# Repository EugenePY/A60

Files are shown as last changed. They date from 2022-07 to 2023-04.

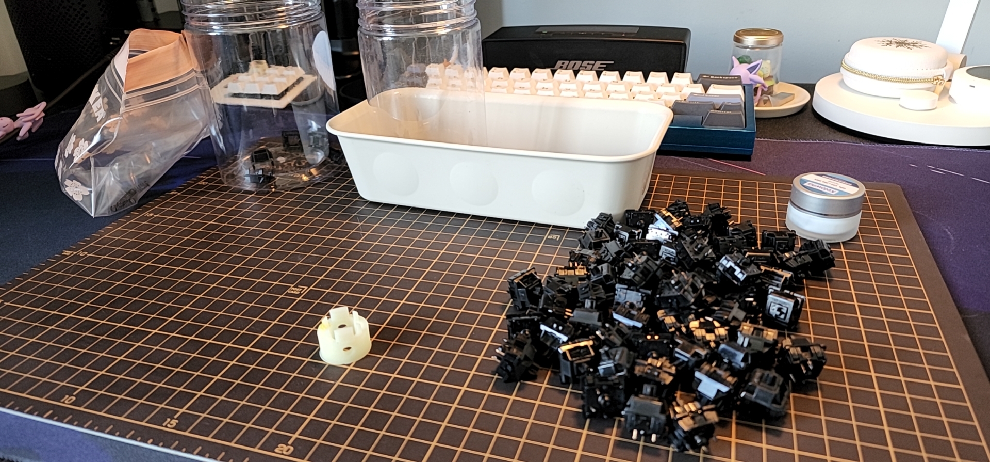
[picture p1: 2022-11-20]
Photo Shoots/wx_camera_1661579096359.jpg

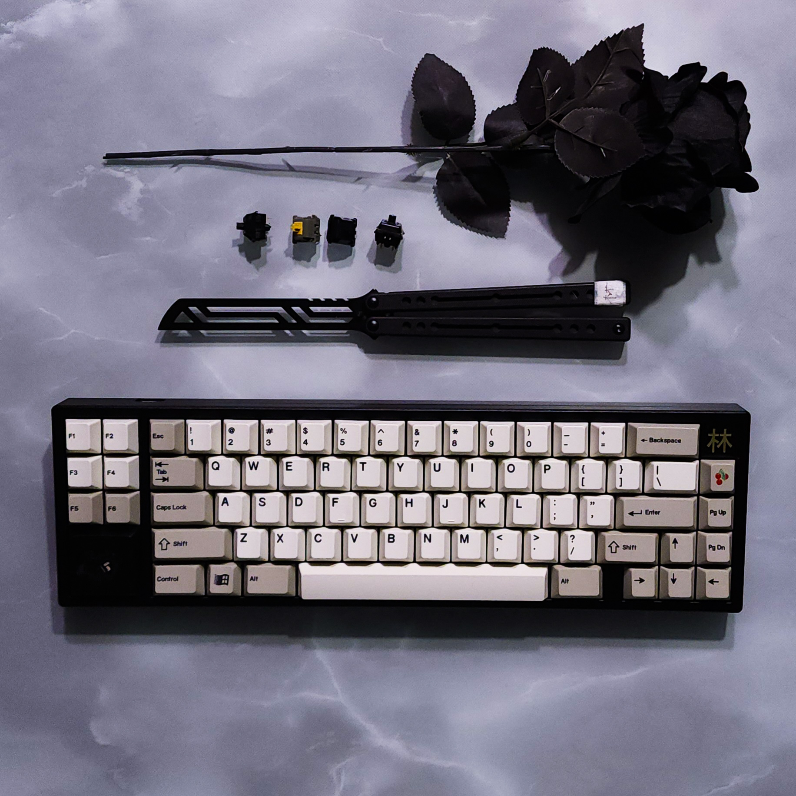
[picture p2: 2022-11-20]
Photo Shoots/20221017_020129.jpg

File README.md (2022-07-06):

# Forest 65 PCB

Hi, Andrew nice work!

Since you are using the web based eda tool, I generaly do not have any problems 
with them. It's very simple and having great integration with the pcb/eletronic 
component firms, but I suggest you still need to learn KiCAD, 

There are few benifit about kicad. 

1. it's open sourced.
2. it has a great supported by the eda/keyboard community.

Most of open sourced EE project are using kicad as their tools, and some of 
professional still prefer it to some commercial EDAs like EAGLE, Altium. 

there are many learning resource for kicad, one of most popular one is the 
[Ai03's Keyboard Guide](https://wiki.ai03.com/books/pcb-design/page/pcb-guide-part-1---preparations)

You may follow it to know how to use kicad. Kicad also has a lot of open sourced footprint libarary.

1. [Ai03's Mx Switch Footprint](https://github.com/ai03-2725/MX_Alps_Hybrid.git)
2. [Acherion Project Gondolindrim](https://github.com/AcheronProject)

# For current PCB files

I  add datasheet about ATMEGA32U4-AU, you can check your pins, reading the 
datasheet maybe very overwhelming in the first place, but I still recommanded 
to go through it. It's very benifitcial for you in the long run since you want 
to get into eletronic desin/EE. And other datasheet follows the similar priciple.

# TODOs

1. Please rewire your pcb in kicad.

# PCB comments

I think your pcb works, but there are few things need to be improved.
    
### The wire should not be too close to the pcb edge if the space allowed. 

    If the wire are too close to the edge it may break easily, but it just a 
    minor things to notice, generaly it does not affect overall functionality.

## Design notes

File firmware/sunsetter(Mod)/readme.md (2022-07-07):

# Sunsetter

Sunsetter

A 65 + 10% F-Key Column Keyboard kit made and sold by Charue Design. [More info on charue-design.com](https://charue-design.com/)

* Keyboard Maintainer: [Coarse](https://github.com/coarse)
* Hardware Supported: [Sunsetter PCB](https://charue-design.com/collections/sunsetter/products/sunsetter-pcb-extra)
* Hardware Availability: [Charue Design](https://charue-design.com/)

#### Jumping to Bootloader

To enter the bootloader, you may use bootmagic by holding `Space+B` or by holding the reset button located at the back of the PCB, right beside the left shift key, for a few seconds.

Make example for this keyboard (after setting up your build environment):

    make charue/sunsetter:default

See the [build environment setup](https://docs.qmk.fm/#/getting_started_build_tools) and the [make instructions](https://docs.qmk.fm/#/getting_started_make_guide) for more information. Brand new to QMK? Start with our [Complete Newbs Guide](https://docs.qmk.fm/#/newbs).

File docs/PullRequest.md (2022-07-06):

# A60-PCB

If you are using github gui, I suggest you using commandline, haha.

[some basics](https://www.earthdatascience.org/workshops/intro-version-control-git/basic-git-commands/)

__To make me to have your code in my repo(Create a pull request to upstream repo)__ 

there are few steps to do.

1. Fork my project
2. Clone your repo
3. Add your pcb files to your repo, and commit it in the git tree.
4. Create a pull request to my repo.

# Fork my project

Since the repo is public, so the project can be accessed for everyone. The 
first step to collabration with other developer is to fork their project. 
Forking a project means to create a parallel branch. It can be seen as your version of source code.

Please read the following document for further details about how fork my project.
https://www.earthdatascience.org/workshops/intro-version-control-git/about-forks/

# Clone Your project

Once you create a fork of my project, you should see a new repo in your own 
github accout, and the content is same as mine. Please clone the repo from your own github account.

```
git clone https://github.com/YOUR-USERNAME/YOUR-REPOSITORY
```

you should type in your commandline or terminal.

```
git clone https://github.com/TimalU27/A60.git
```

# Add pcb files to your repo and commit your changes.

then add your sorce code to the git tree.

the add files to your repo please type following command. the command means 
add all files under your root directory.

```
git add .
```

to commit 

```
git commit -m "your commit message"
```

# Create a pull request to my repo.

[How to do a github pull request](https://stackoverflow.com/questions/14680711/how-to-do-a-github-pull-request)

good luck.

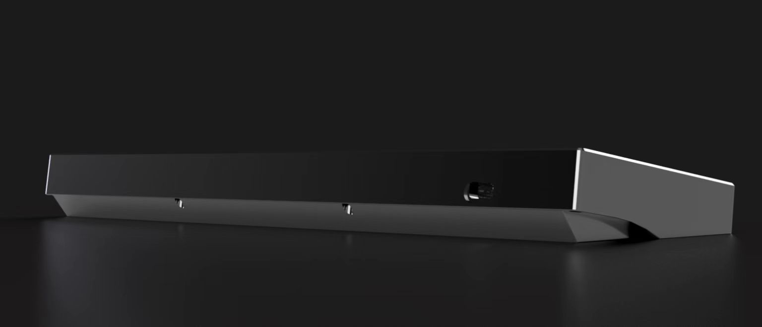
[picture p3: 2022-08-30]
render/render v2/Back.jpg

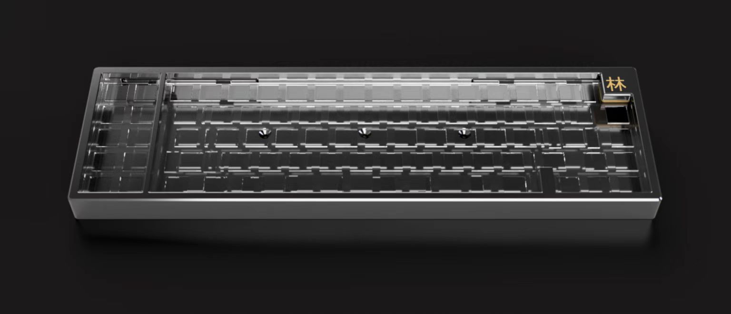
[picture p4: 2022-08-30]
render/render v2/Top.jpg

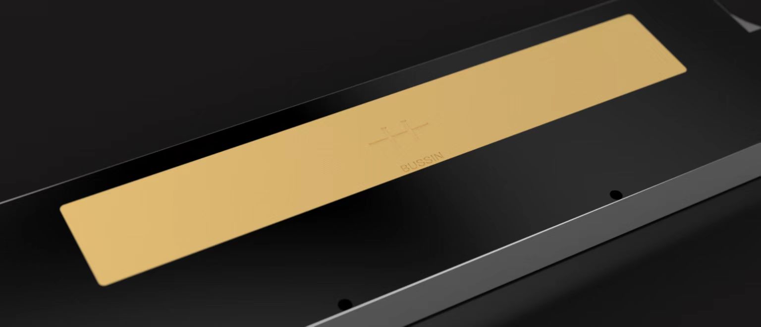
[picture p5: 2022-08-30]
render/render v2/Weight.jpg

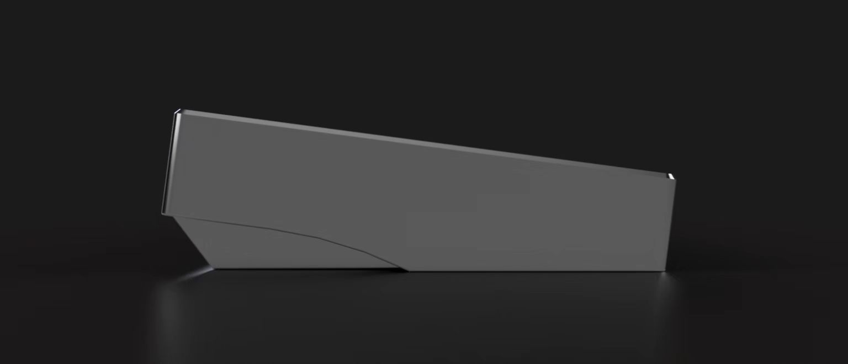
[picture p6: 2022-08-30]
render/render v2/side.jpg

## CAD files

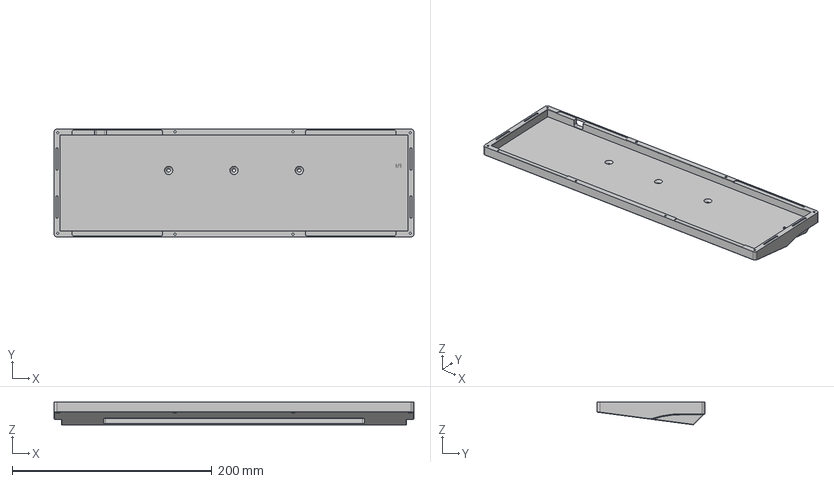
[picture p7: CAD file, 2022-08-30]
3d/bottom.step
360.6 x 108.2 x 22.7 mm

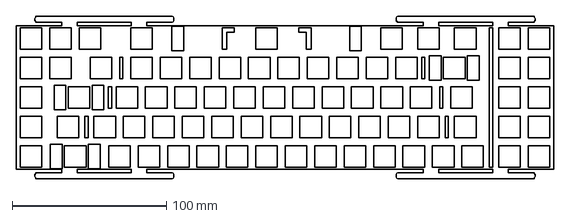
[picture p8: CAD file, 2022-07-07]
plate felx.dxf
347.7 x 105.2 mm

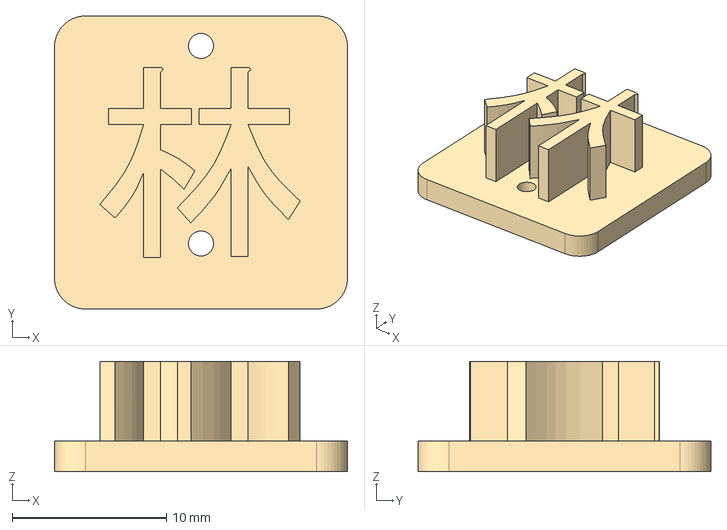
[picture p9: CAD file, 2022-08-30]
3d/badge.step
19.0 x 19.0 x 7.15 mm

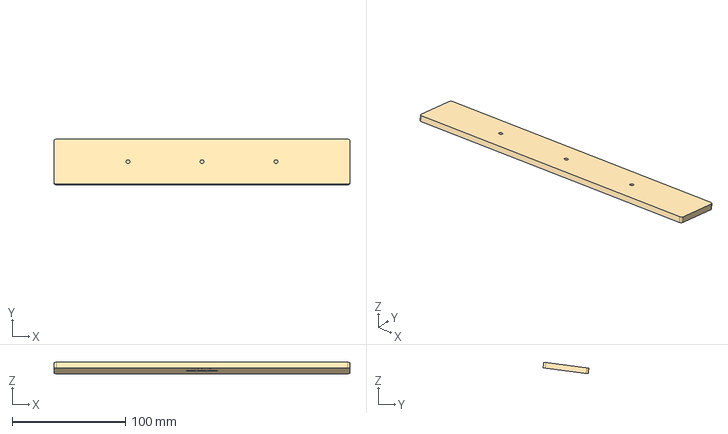
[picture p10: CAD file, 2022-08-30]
3d/Weight.step
261.7 x 40.6 x 10.2 mm

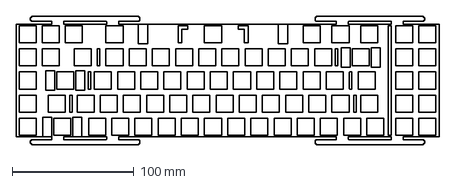
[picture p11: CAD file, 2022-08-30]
3d/plate.dxf
347.7 x 105.2 mm

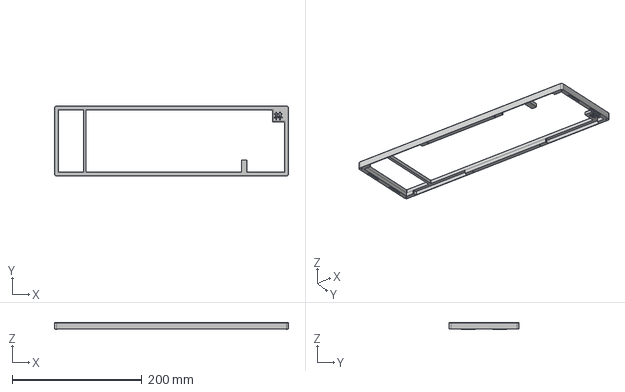
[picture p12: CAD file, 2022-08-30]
3d/top.step
360.6 x 108.2 x 11.5 mm

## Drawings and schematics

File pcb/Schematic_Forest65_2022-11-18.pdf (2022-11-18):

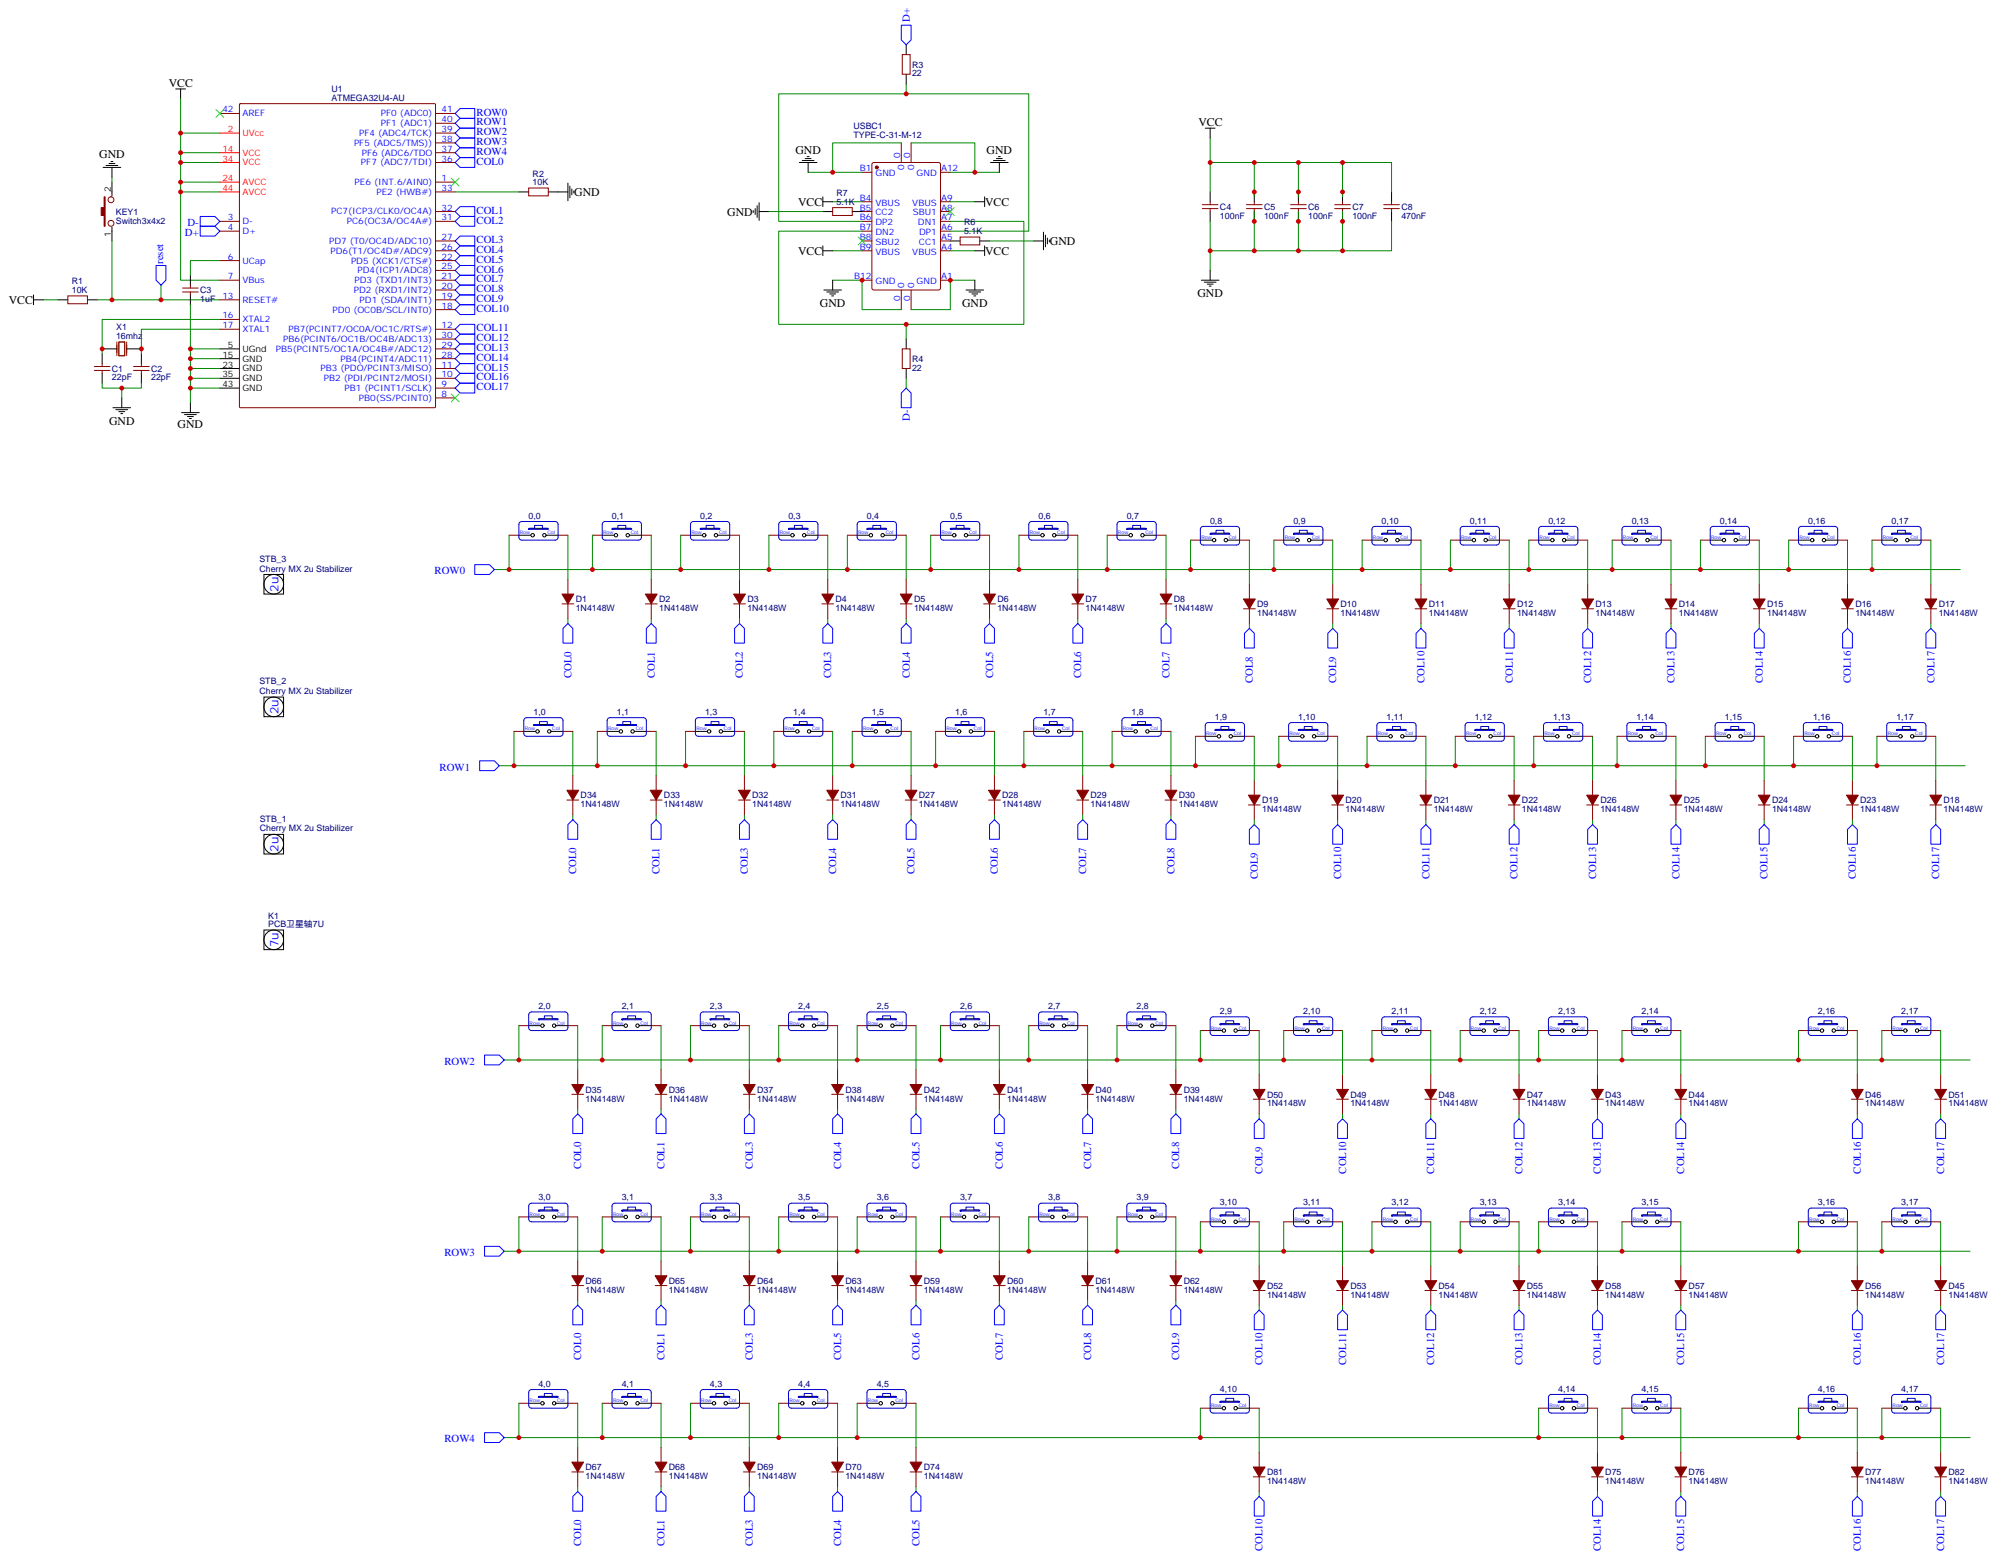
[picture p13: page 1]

PB7(PCINT7/OC0A/OC1C/RTS#) 12
PB2 (PDI/PCINT2/MOSI) 10 PB3 (PDO/PCINT3/MISO) 11 PB4(PCINT4/ADC11) 28 PB5(PCINT5/OC1A/OC4B#/ADC12) 29 PB6(PCINT6/OC1B/OC4B/ADC13) 30

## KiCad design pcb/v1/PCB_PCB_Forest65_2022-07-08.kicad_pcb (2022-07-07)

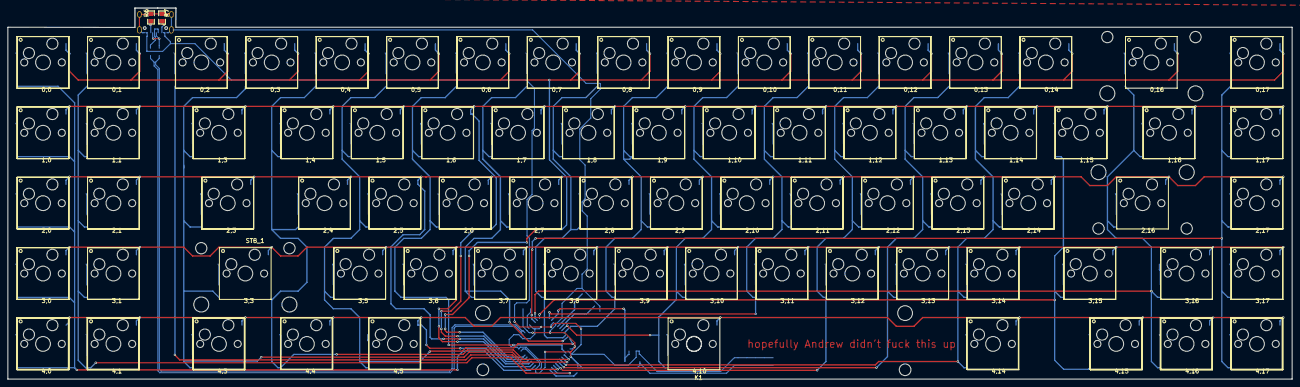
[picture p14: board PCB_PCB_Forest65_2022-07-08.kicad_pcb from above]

Board: 2 copper layers, 347.7 x 100.4 mm, 174 parts (0 on the bottom side), 112 nets.

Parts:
0,0, 0,1, 0,2, 0,3, 0,4, 0,5, 0,6, 0,7, 0,8, 0,9, 0,10, 0,11, 0,12, 0,13, 0,14, 0,16, 0,17, 1,0, 1,1, 1,3, 1,4, 1,5, 1,6, 1,7, 1,8, 1,9, 1,10, 1,11, 1,12, 1,13, 1,14, 1,15, 1,16, 1,17, 2,0, 2,1, 2,3, 2,4, 2,5, 2,6, 2,7, 2,8, 2,9, 2,10, 2,11, 2,12, 2,13, 2,14, 2,16, 2,17, 3,0, 3,1, 3,3, 3,5, 3,6, 3,7, 3,8, 3,9, 3,10, 3,11, 3,12, 3,13, 3,14, 3,15, 3,16, 3,17, 4,0, 4,1, 4,3, 4,4, 4,5, 4,10, 4,14, 4,15, 4,16, 4,17: 凯华热插拔; 凯华热插拨
C1, C2: 22pF; C0805
C3: 1uF; C0805
C4, C5, C6, C7: 100nF; C0805
C8: 470nF; C0805
D1, D2, D3, D4, D5, D6, D7, D8, D9, D10, D11, D12, D13, D14, D15, D16, D17, D18, D19, D20, D21, D22, D23, D24, D25, D26, D27, D28, D29, D30, D31, D32, D33, D34, D35, D36, D37, D38, D39, D40, D41, D42, D43, D44, D45, D46, D47, D48, D49, D50, D51, D52, D53, D54, D55, D56, D57, D58, D59, D60, D61, D62, D63, D64, D65, D66, D67, D68, D69, D70, D74, D75, D76, D77, D81, D82: 1N4148W; SOD-123_L2.8-W1.8-LS3.7-RD
K1: PCB卫星轴7U; CHERRY_MX_7U
KEY1: Switch3x4x2; SW-SMD_L4.0-W2.9-LS5.0
R1, R2: 10K; R0805
R3, R4: 22; R0805
R6, R7: 5.1K; R0805
STB_1, STB_2, STB_3: Cherry MX 2u Stabilizer; MX1A STABILIZER 2U
U1: ATMEGA32U4-AU; QFP-44_L10.0-W10.0-P0.80-LS13.2-BL
USBC1: TYPE-C-31-M-12; USB-C_SMD-TYPE-C-31-M-12
X1: 16mhz; OSC-SMD_2P-L5.0-W3.2

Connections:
0,0_K2: 0,0.K2, D1.2
0,2_K2: 0,2.K2, D3.2
0,5_K2: 0,5.K2, D6.2
0,7_K2: 0,7.K2, D8.2
0,9_K2: 0,9.K2, D10.2
0,11_K2: 0,11.K2, D12.2
0,12_K2: 0,12.K2, D13.2
0,14_K2: 0,14.K2, D15.2
0,17_K2: 0,17.K2, D17.2
1,1_K2: 1,1.K2, D33.2
1,4_K2: 1,4.K2, D31.2
1,5_K2: 1,5.K2, D27.2
1,7_K2: 1,7.K2, D29.2
1,9_K2: 1,9.K2, D19.2
1,11_K2: 1,11.K2, D21.2
1,14_K2: 1,14.K2, D25.2
1,16_K2: 1,16.K2, D23.2
2,0_K2: 2,0.K2, D35.2
2,6_K2: 2,6.K2, D41.2
2,8_K2: 2,8.K2, D39.2
2,10_K2: 2,10.K2, D49.2
2,12_K2: 2,12.K2, D47.2
2,13_K2: 2,13.K2, D43.2
2,17_K2: 2,17.K2, D51.2
3,1_K2: 3,1.K2, D65.2
3,5_K2: 3,5.K2, D63.2
3,6_K2: 3,6.K2, D59.2
3,8_K2: 3,8.K2, D61.2
3,10_K2: 3,10.K2, D52.2
3,12_K2: 3,12.K2, D54.2
3,15_K2: 3,15.K2, D57.2
3,16_K2: 3,16.K2, D56.2
4,0_K2: 4,0.K2, D67.2
4,3_K2: 4,3.K2, D69.2
4,14_K2: 4,14.K2, D75.2
4,17_K2: 4,17.K2, D82.2
COL0: D1.1, D34.1, D35.1, D66.1, D67.1, U1.36
COL1: D2.1, D33.1, D36.1, D65.1, D68.1, U1.32
COL2: D3.1, U1.31
COL3: D4.1, D32.1, D37.1, D64.1, D69.1, U1.27
COL4: D5.1, D31.1, D38.1, D70.1, U1.26
COL5: D6.1, D27.1, D42.1, D63.1, D74.1, U1.22
COL6: D7.1, D28.1, D41.1, D59.1, U1.25
COL7: D8.1, D29.1, D40.1, D60.1, U1.21
COL8: D9.1, D30.1, D39.1, D61.1, U1.20
COL9: D10.1, D19.1, D50.1, D62.1, U1.19
COL10: D11.1, D20.1, D49.1, D52.1, D81.1, U1.18
COL11: D12.1, D21.1, D48.1, D53.1, U1.12
COL12: D13.1, D22.1, D47.1, D54.1, U1.30
COL13: D14.1, D26.1, D43.1, D55.1, U1.29
COL14: D15.1, D25.1, D44.1, D58.1, D75.1, U1.28
COL15: D24.1, D57.1, D76.1, U1.11
COL16: D16.1, D23.1, D46.1, D56.1, D77.1, U1.10
COL17: D17.1, D18.1, D45.1, D51.1, D82.1, U1.9
D2_2: 0,1.K2, D2.2
D4_2: 0,3.K2, D4.2
D5_2: 0,4.K2, D5.2
D7_2: 0,6.K2, D7.2
D9_2: 0,8.K2, D9.2
D11_2: 0,10.K2, D11.2
D14_2: 0,13.K2, D14.2
D16_2: 0,16.K2, D16.2
D18_2: 1,17.K2, D18.2
D20_2: 1,10.K2, D20.2
D22_2: 1,12.K2, D22.2
D24_2: 1,15.K2, D24.2
D26_2: 1,13.K2, D26.2
D28_2: 1,6.K2, D28.2
D30_2: 1,8.K2, D30.2
D32_2: 1,3.K2, D32.2
D34_2: 1,0.K2, D34.2
D36_2: 2,1.K2, D36.2
D37_2: 2,3.K2, D37.2
D38_2: 2,4.K2, D38.2
D40_2: 2,7.K2, D40.2
D42_2: 2,5.K2, D42.2
D44_2: 2,14.K2, D44.2
D45_2: 3,17.K2, D45.2
D46_2: 2,16.K2, D46.2
D48_2: 2,11.K2, D48.2
D50_2: 2,9.K2, D50.2
D53_2: 3,11.K2, D53.2
D55_2: 3,13.K2, D55.2
D58_2: 3,14.K2, D58.2
D60_2: 3,7.K2, D60.2
D62_2: 3,9.K2, D62.2
D64_2: 3,3.K2, D64.2
D66_2: 3,0.K2, D66.2
D68_2: 4,1.K2, D68.2
D70_2: 4,4.K2, D70.2
D74_2: 4,5.K2, D74.2
D76_2: 4,15.K2, D76.2
D77_2: 4,16.K2, D77.2
D81_2: 4,10.K2, D81.2
D+: R4.1, U1.4
D-: R3.2, U1.3
GND: C1.1, C2.1, C3.1, C4.1, C5.1, C6.1, C7.1, C8.2, KEY1.2, R2.2, R6.2, R7.1, U1.5, U1.15, U1.23, U1.35, U1.43, USBC1.0, USBC1.A1, USBC1.A12, USBC1.B1, USBC1.B12
RESET: KEY1.1, R1.2, U1.13
ROW0: 0,0.K1, 0,1.K1, 0,2.K1, 0,3.K1, 0,4.K1, 0,5.K1, 0,6.K1, 0,7.K1, 0,8.K1, 0,9.K1, 0,10.K1, 0,11.K1, 0,12.K1, 0,13.K1, 0,14.K1, 0,16.K1, 0,17.K1, U1.41
ROW1: 1,0.K1, 1,1.K1, 1,3.K1, 1,4.K1, 1,5.K1, 1,6.K1, 1,7.K1, 1,8.K1, 1,9.K1, 1,10.K1, 1,11.K1, 1,12.K1, 1,13.K1, 1,14.K1, 1,15.K1, 1,16.K1, 1,17.K1, U1.40
ROW2: 2,0.K1, 2,1.K1, 2,3.K1, 2,4.K1, 2,5.K1, 2,6.K1, 2,7.K1, 2,8.K1, 2,9.K1, 2,10.K1, 2,11.K1, 2,12.K1, 2,13.K1, 2,14.K1, 2,16.K1, 2,17.K1, U1.39
ROW3: 3,0.K1, 3,1.K1, 3,3.K1, 3,5.K1, 3,6.K1, 3,7.K1, 3,8.K1, 3,9.K1, 3,10.K1, 3,11.K1, 3,12.K1, 3,13.K1, 3,14.K1, 3,15.K1, 3,16.K1, 3,17.K1, U1.38
ROW4: 4,0.K1, 4,1.K1, 4,3.K1, 4,4.K1, 4,5.K1, 4,10.K1, 4,14.K1, 4,15.K1, 4,16.K1, 4,17.K1, U1.37
U1_6: C3.2, U1.6
U1_16: C1.2, U1.16, X1.1
U1_17: C2.2, U1.17, X1.2
U1_33: R2.1, U1.33
USBC1_A5: R6.1, USBC1.A5
USBC1_B5: R7.2, USBC1.B5
USBC1_B6: R3.1, USBC1.A6, USBC1.B6
USBC1_B7: R4.2, USBC1.A7, USBC1.B7
VCC: C4.2, C5.2, C6.2, C7.2, C8.1, R1.1, U1.2, U1.7, U1.14, U1.24, U1.34, U1.44, USBC1.A4, USBC1.A9, USBC1.B4, USBC1.B9

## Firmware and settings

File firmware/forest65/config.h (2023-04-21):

#ifndef CONFIG_H
#define CONFIG_H

#include "config_common.h"

/* USB Device descriptor parameter */
#define VENDOR_ID       0x1127
#define PRODUCT_ID      0x6060
#define DEVICE_VER      0x0001
#define MANUFACTURER    Timal
#define PRODUCT         Forest65

/* key matrix size */
#define MATRIX_ROWS 5
#define MATRIX_COLS 18

/* key matrix pins */
#define MATRIX_ROW_PINS { F0, F1, F4, F5, F6 }
#define MATRIX_COL_PINS { F7, C7, C6, D7, D6, D5, D4, D3, D2, D1, D0, B7, B6, B5, B4, B3, B2, B1 }

/* COL2ROW or ROW2COL */
#define DIODE_DIRECTION ROW2COL

/* number of backlight levels */

#ifdef BACKLIGHT_PIN
#define BACKLIGHT_LEVELS 3
#endif

/* Set 0 if debouncing isn't needed */
#define DEBOUNCING 5

/* Mechanical locking support. Use KC_LCAP, KC_LNUM or KC_LSCR instead in keymap */
#define LOCKING_SUPPORT_ENABLE

/* Locking resynchronize hack */
#define LOCKING_RESYNC_ENABLE

/* key combination for command */
#define IS_COMMAND() ( \
    keyboard_report->mods == (MOD_BIT(KC_LSHIFT) | MOD_BIT(KC_RSHIFT)) \
)


#ifdef RGB_DI_PIN
#define RGBLED_NUM 0
#define RGBLIGHT_HUE_STEP 8
#define RGBLIGHT_SAT_STEP 8
#define RGBLIGHT_VAL_STEP 8
#endif

#endif

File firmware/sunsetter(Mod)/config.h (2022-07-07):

/*
Copyright 2020 Michael Pio "Coarse" Mayol  <mfmayol@up.edu.ph>

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
You should have received a copy of the GNU General Public License
along with this program.  If not, see <http://www.gnu.org/licenses/>.
*/

#pragma once

/* USB Device descriptor parameter */
#define VENDOR_ID       0x4344 // CD for CharueDesign
#define PRODUCT_ID      0x5353 // SS for Sunsetter
#define DEVICE_VER      0x0001 // Revision prototype
#define MANUFACTURER    CharueDesign
#define PRODUCT         Sunsetter

/* key matrix size */
#define MATRIX_ROWS 5
#define MATRIX_COLS 18

#define MATRIX_ROW_PINS { F0, F1, F4, F5, F6 }
#define MATRIX_COL_PINS { F7, C7, C6, D7, D6, D5, D4, D3, D2, D1, D0, B7, B6, B5, B4, B3, B2, B1 }
#define DIODE_DIRECTION ROW2COL
/* Set 0 if debouncing isn't needed */
#define DEBOUNCE    5

#define LED_CAPS_LOCK_PIN B0
#define LED_PIN_ON_STATE 0

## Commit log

2022-07-05 the pcb files
    Thanks a lot man!
    我用的軟體是立創eda因爲他們從畫圖到生產一套系統在中國很方便
    just incase if it might not work
    我有轉一個kicad的版本但是原理圖沒辦法一起轉所以我把它導出成一個pdf了
    also 我後來研究了一下最後使用的是GitHub desktop 還蠻簡單易懂的
    gn!
    [PCB_Forest65.kicad_pcb]
2022-07-07 Firmware files
    [PCB_Forest65.kicad_pcb]
2022-07-07 pcb route fix
    [PCB_Forest65.kicad_pcb, PCB_PCB_Forest65_2022-07-08.kicad_pcb]
2022-07-07 Firmware is now compilable
    roughly modded the Sunsetter firmware
    [plate felx.dxf]
2022-07-24 lower case
2022-07-24 more lower case fix
    [config.h]
2022-08-30 add STEP files
    [Weight.step, badge.step, bottom.step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]
2022-11-18 update pcb files

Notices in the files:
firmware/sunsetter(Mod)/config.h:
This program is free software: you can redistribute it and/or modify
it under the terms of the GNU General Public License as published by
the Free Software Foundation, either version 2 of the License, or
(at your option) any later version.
